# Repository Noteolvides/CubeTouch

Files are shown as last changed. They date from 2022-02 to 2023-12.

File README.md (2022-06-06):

## What is it?
A cube made up of 6 PCBs that when soldered together form a cube universe.
CubeTouch is designed to create a beautiful object from PCBs but giving it all the functionality of a HID device, being able to interact with the computer as if it were a keyboard or any other HID device. 

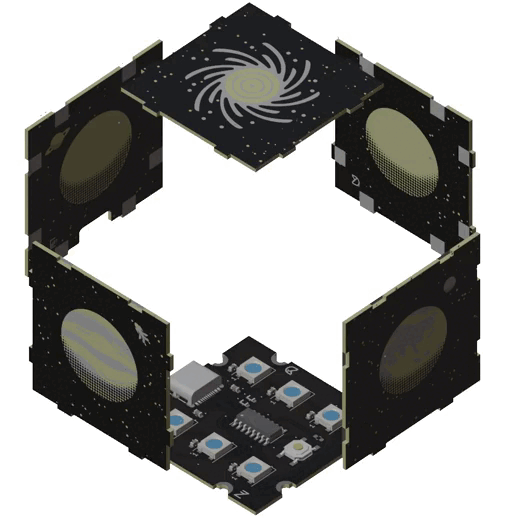
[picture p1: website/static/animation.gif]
Insert Photo here enter image title here


CubeTouch is made up of the **CH552** micontroller and 6 WS2812 LEDs that illuminate the planets thanks to the diffusion of the FR4 material. This device is already loaded with a firmware that when pressing one of the 5 planets will send a combination of keys to the computer. These can be modified on the 

# Documentation and more
CubeTouch has its own [webPage](https://cubetouch.noteolvid.es/) where you can find, how to [program the device](https://cubetouch.noteolvid.es/docs/firstSteps/programming/), [examples](https://cubetouch.noteolvid.es/docs/firstSteps/examples/) and much more😊!

## Examples
### Custom Firmware
Default firmware that comes preload with the package. Its main function is to use as an external keyboard with shortcuts to increase your productivity in your daily work in the computer.
Each face is mapped with a possible combination of 3 keys, and a color to show that the keys were sent.
These can be remapped via the [web interface](https://cubetouch.noteolvid.es/keyRemapping/) thanks to [web serial](https://web.dev/serial/).
### [Easy RGB](https://cubetouch.noteolvid.es/docs/firstSteps/examples/#easy-rgb)
A simple example that receives an RGB hex value and displays it. Send hex color to the Serial Monitor following this format (R,G,B): #0B4F02
### [Chasse Lights](https://cubetouch.noteolvid.es/docs/firstSteps/examples/#chasse-text)
Moving lights.
### [Easy Touch](https://cubetouch.noteolvid.es/docs/firstSteps/examples/#easy-touch)
A simple example that when a face is touch prints the face that has received input from.
### [CDC and Keyboard](https://cubetouch.noteolvid.es/docs/firstSteps/examples/#cdc-and-keyboard)
This example echoes the next character of data it receives via the serial monitor and sends as a key also the next character send.
### [Custom Bootloader](https://cubetouch.noteolvid.es/docs/firstSteps/examples/#custom-bootloader)
This example that shows how to jump to the bootloader address to make it reprogrammable. You can send the character B, or connect the pin 11 to GND.

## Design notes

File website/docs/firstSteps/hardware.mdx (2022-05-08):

---
sidebar_position: 2
---

# Hardware

## Pinout
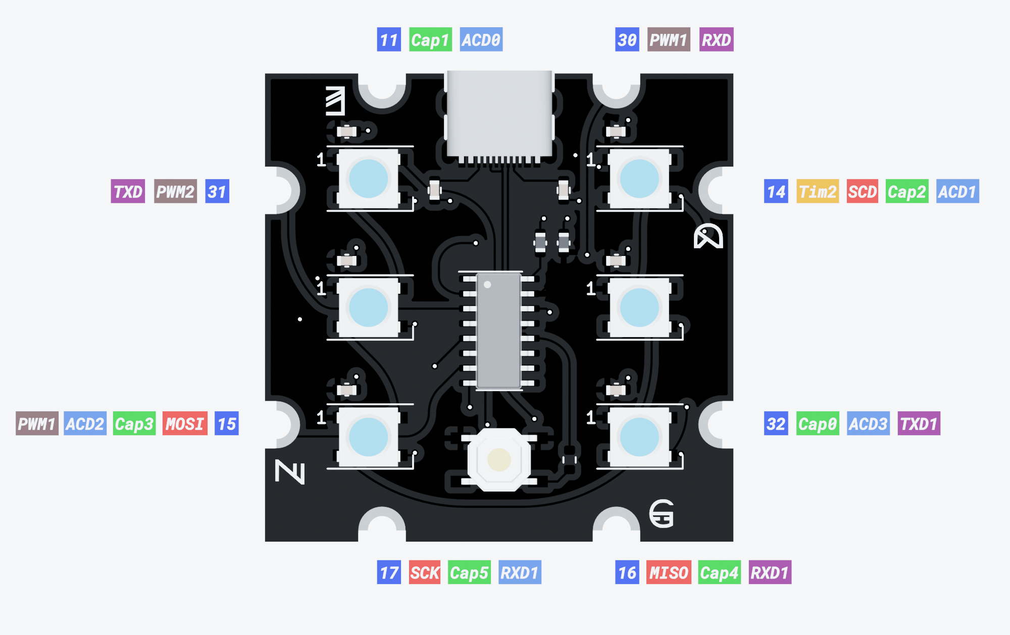
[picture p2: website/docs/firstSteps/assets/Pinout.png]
Pinout


[//]: # (TODO: Add here table with pin capabilities)

## BOM
| **Qty** | **Value** | **LCSC** | **Reference(s)** |
|:---:|:---:|:---:|:---:|
| 8 |  Capacitor 0,1uf  |  C14663  | C1, C2, C3, C4, C5, C6, C7, C8 |
| 6 | WS2812B |  C139127 | D1, D2, D3, D4, D5, D6 |
| 1 | USB_C |  C709357 | J1 |
| 2 | Resistor 5.1K |  C25905  | R1, R2 |
| 1 | Resistor 10K |  C25197  | R3 |
| 1 | SW Tactile Button |  C318884 | SW1 |
| 1 | CH554G |  C114295 | U1 |
## Schematics
> :warning: The shematics and pcb are made with the beta version of kicad 5.99

Download the schematic made with kicad in [GitHub](https://github.com/Noteolvides/CubeTouch/tree/main/Hardware/Bottom).
<embed src={require("./assets/salida.pdf").default} width="100%" height="500" type="application/pdf"/>

## PCB'S

### Top
Download the pcb made with kicad in [GitHub](https://github.com/Noteolvides/CubeTouch/tree/main/Hardware/Top).
<div className="container">
  <div className="row" style={{alignItems: "center"}}>
    Pcb Render top
    Pcb Render top back
  </div>
</div>

### Bottom
Download the pcb made with kicad in [GitHub](https://github.com/Noteolvides/CubeTouch/tree/main/Hardware/Bottom).
<div className="container">
  <div className="row" style={{alignItems: "center"}}>
    Pcb Render top
    Pcb Render top back
  </div>
</div>

### Left
Download the pcb made with kicad in [GitHub](https://github.com/Noteolvides/CubeTouch/tree/main/Hardware/Left).
<div className="container">
  <div className="row" style={{alignItems: "center"}}>
    Pcb Render top
    Pcb Render top back
  </div>
</div>

### Right
Download the pcb made with kicad in [GitHub](https://github.com/Noteolvides/CubeTouch/tree/main/Hardware/Right).
<div className="container">
  <div className="row" style={{alignItems: "center"}}>
    Pcb Render top
    Pcb Render top back
  </div>
</div>

### Front
Download the pcb made with kicad in [GitHub](https://github.com/Noteolvides/CubeTouch/tree/main/Hardware/Front).
<div className="container">
  <div className="row" style={{alignItems: "center"}}>
    Pcb Render top
    Pcb Render top back
  </div>
</div>

### Back
Download the pcb made with kicad in [GitHub](https://github.com/Noteolvides/CubeTouch/tree/main/Hardware/Back).
<div className="container">
  <div className="row" style={{alignItems: "center"}}>
    Pcb Render top
    Pcb Render top back
  </div>
</div>

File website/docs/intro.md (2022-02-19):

---
sidebar_position: 1
---

# Welcome to the docs

Let's start learning about **CubeTouch** in less than 5 minutes.

## Getting Started

You can get you own CubeTouch in  **[Tindie](https://docusaurus.new)** there two versions available the already build  one, or you can build it yourself.

If you have gotten build it your shelf version you can check **[here](https://docusaurus.new)** the video and instructions in how to build it.

Once you have your device ready lest start seeing what it can do.

## Features

The CubeTouch is preloaded with a default firmware that shows all the possibles capabilities of this device.
Some of them are:

- Key press emulation, for shortcuts.
- Communication to the computer via WEB Serial.
- Touch capacitive inputs.
- Key remapping via web interface **[here](https://docusaurus.new)**
- Cool RGB lighting (Why not 😝)

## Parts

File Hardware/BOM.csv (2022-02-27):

Reference(s) | Value | LCSC | Qty
C1, C2, C3, C4, C5, C6, C7, C8 | Capacitor 0,1uf | C14663 | 8
D1, D2, D3, D4, D5, D6 | WS2812B | C139127 | 6
J1 | USB_C | C709357 | 1
R1, R2 | Resistor 5.1K | C25905 | 2
R3 | Resistor 10K | C25197 | 1
SW1 | SW Tactile Button | C318884 | 1
U1 | CH554G | C114295 | 1

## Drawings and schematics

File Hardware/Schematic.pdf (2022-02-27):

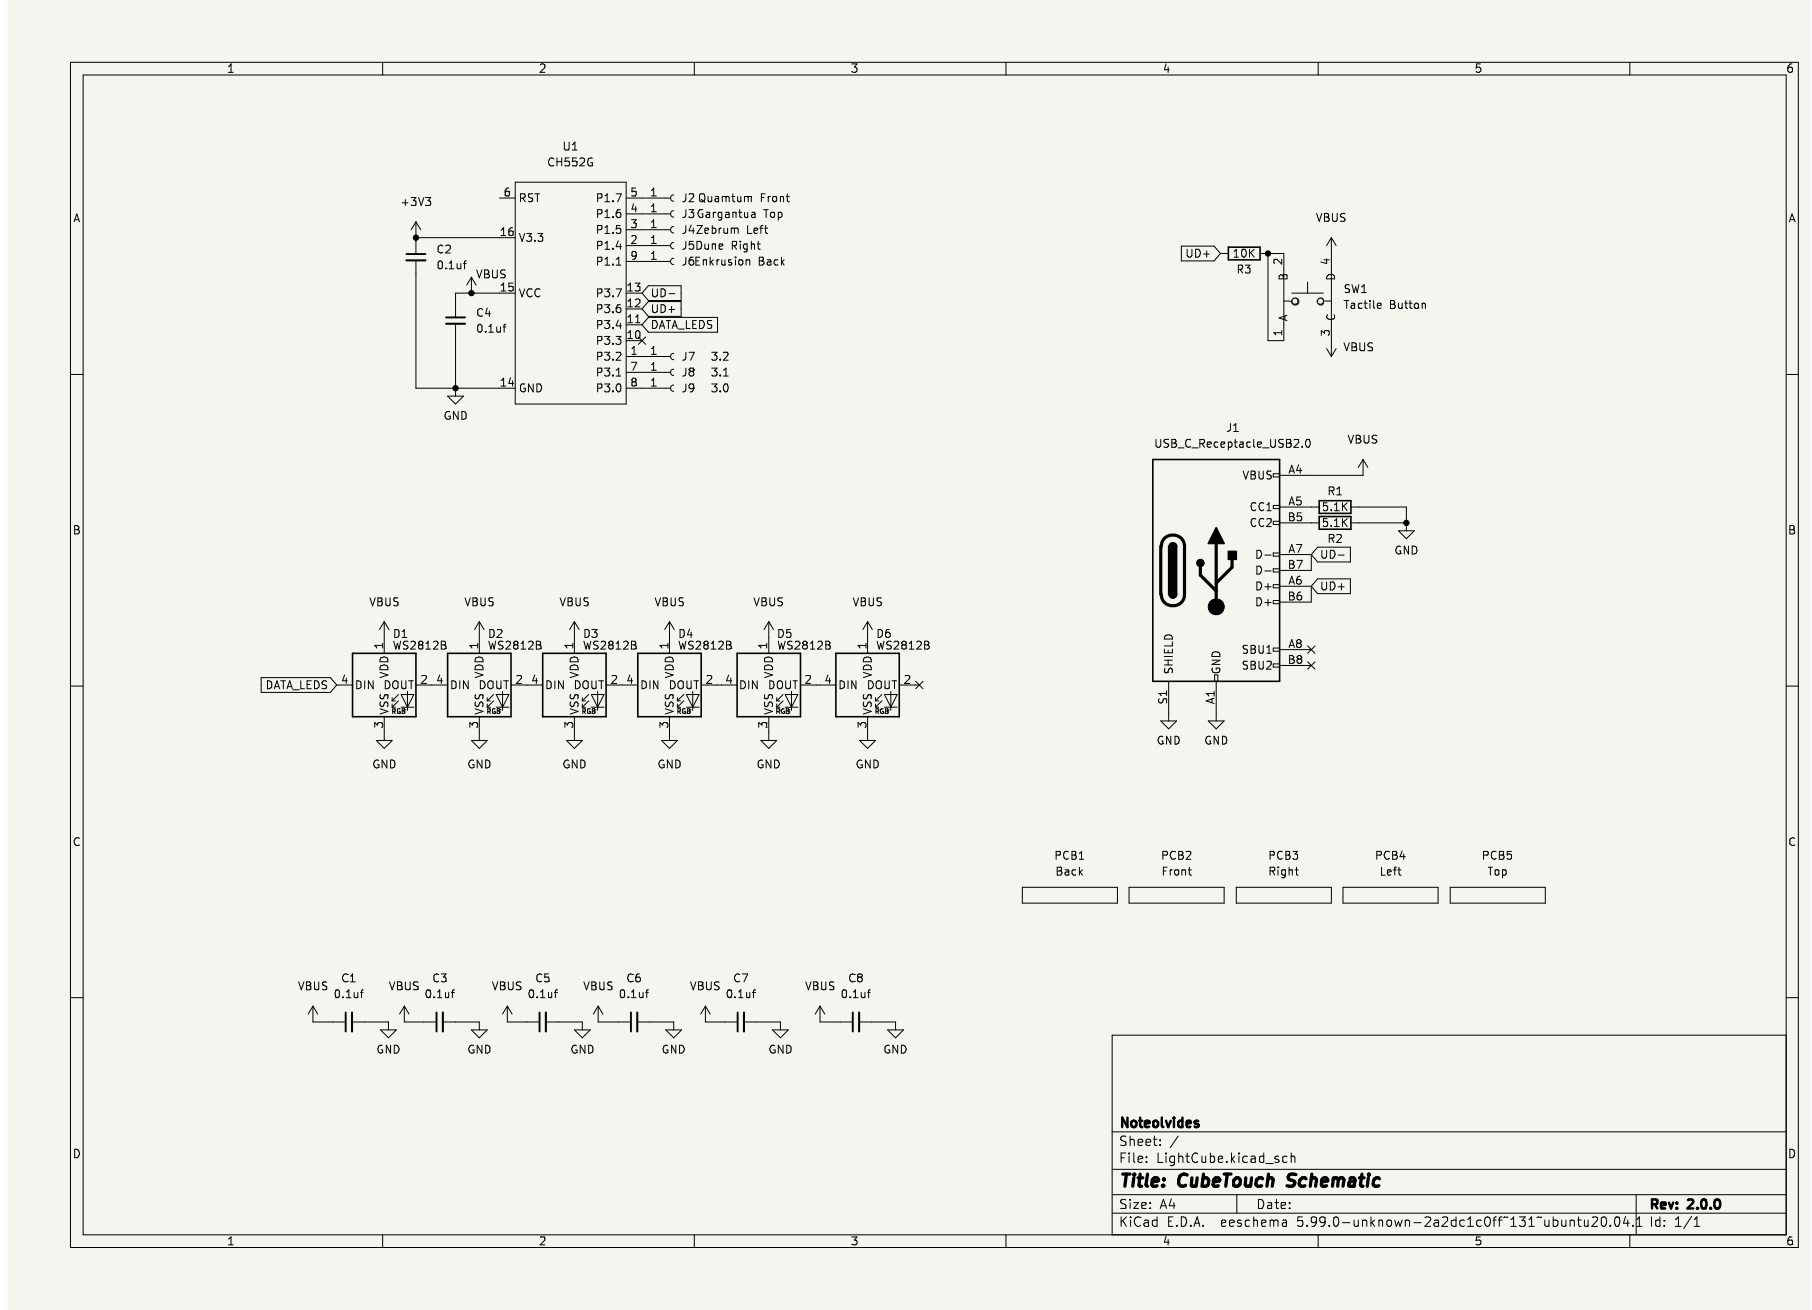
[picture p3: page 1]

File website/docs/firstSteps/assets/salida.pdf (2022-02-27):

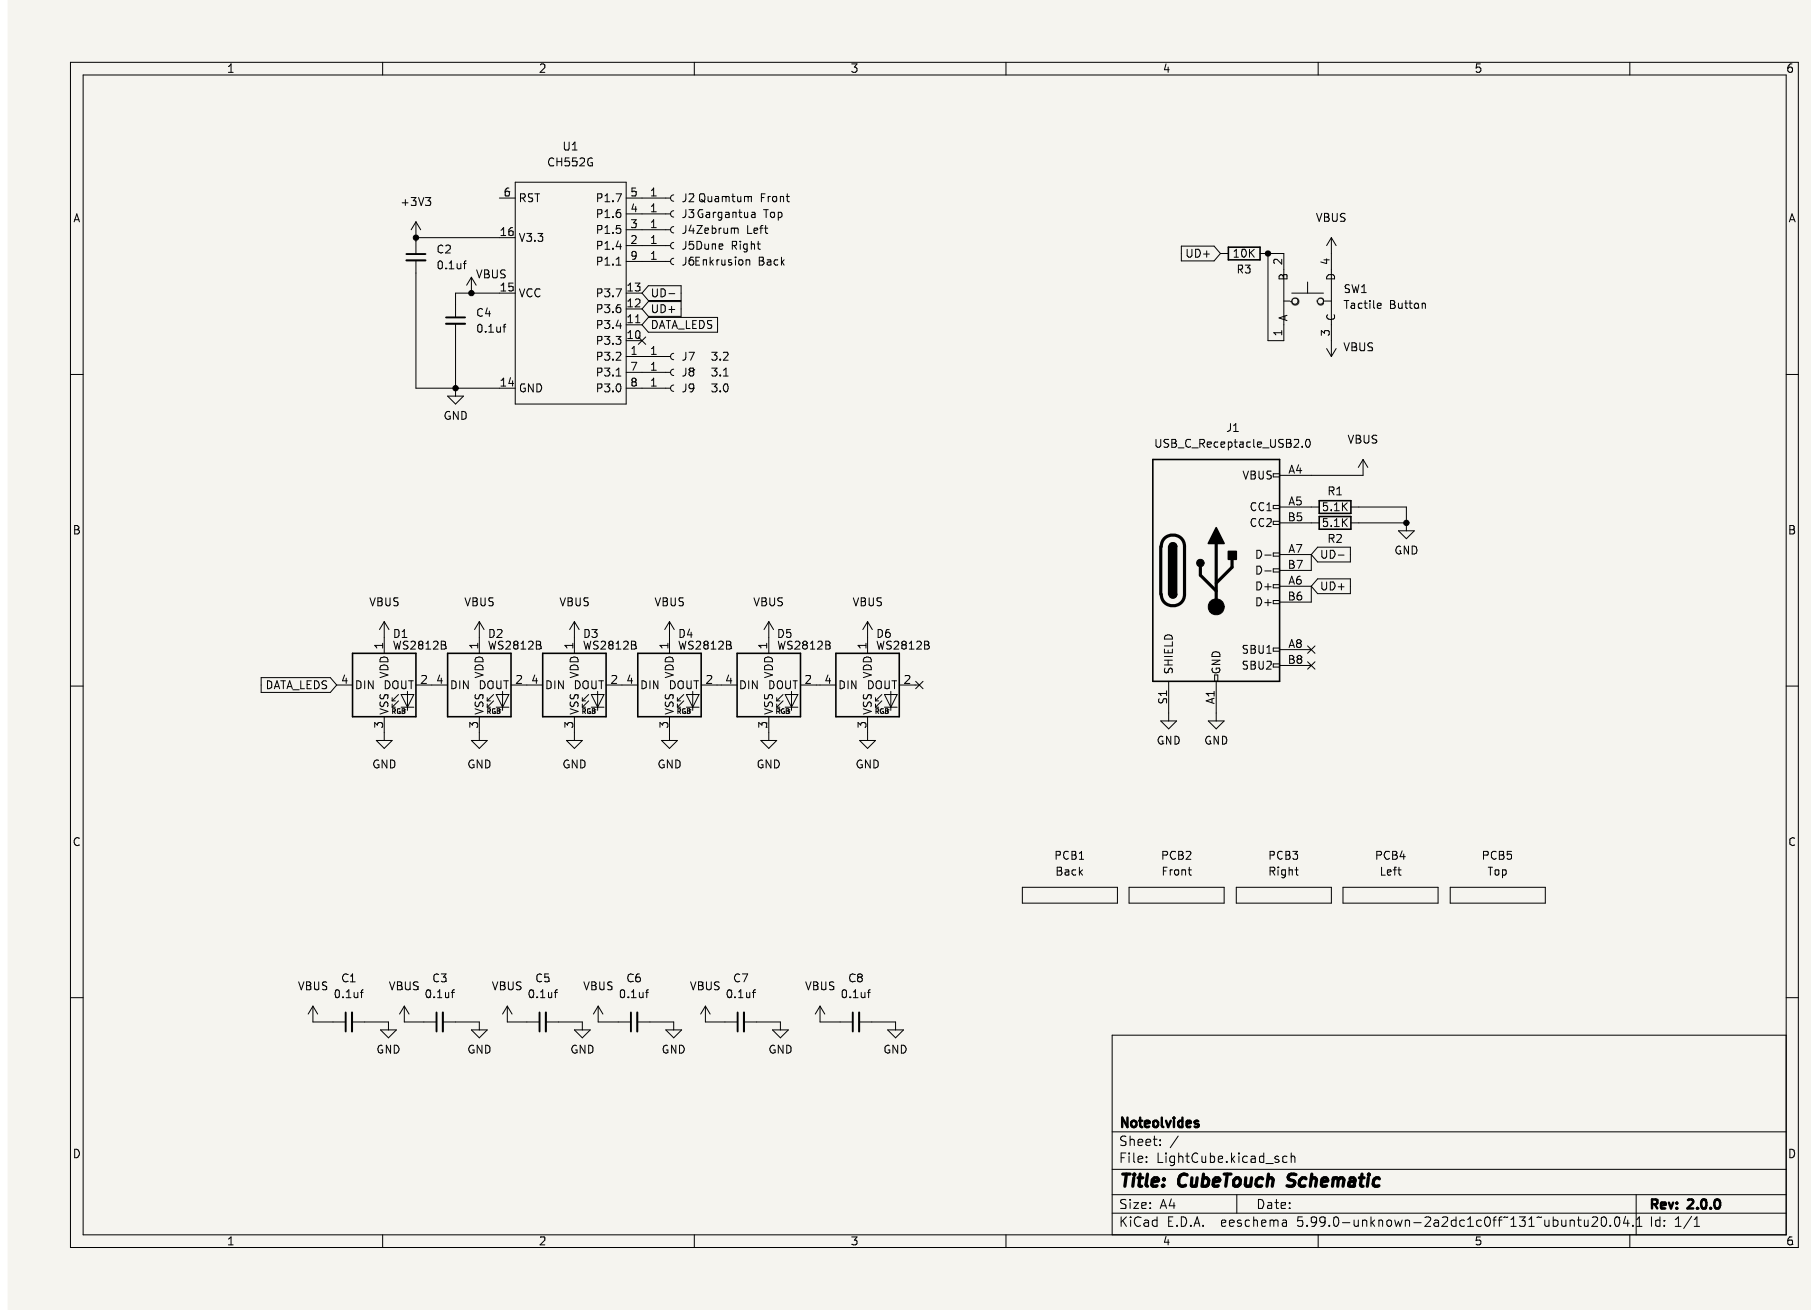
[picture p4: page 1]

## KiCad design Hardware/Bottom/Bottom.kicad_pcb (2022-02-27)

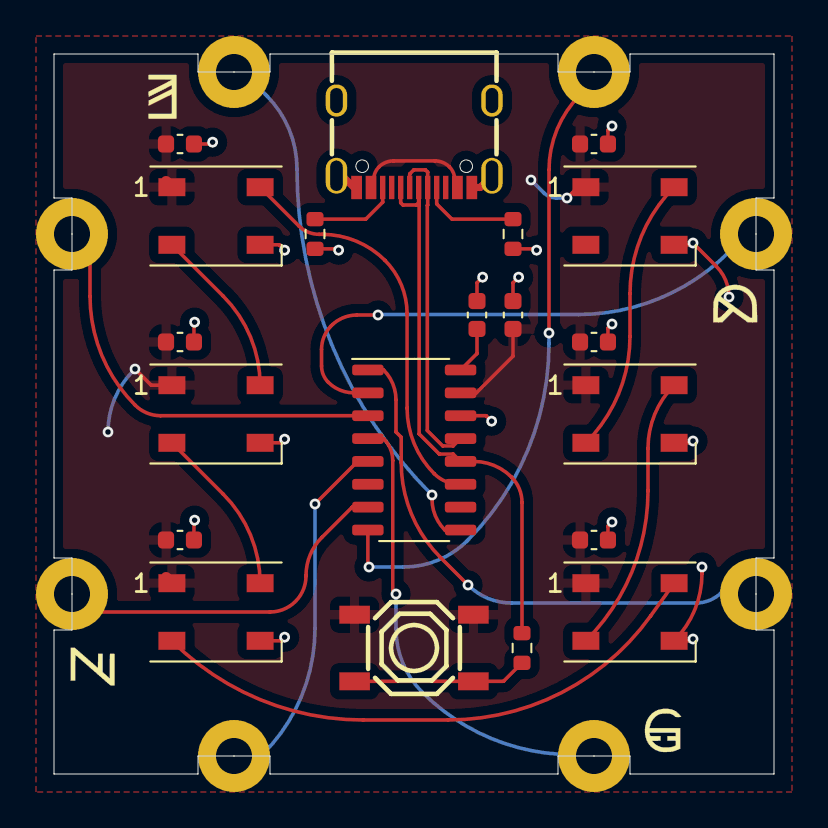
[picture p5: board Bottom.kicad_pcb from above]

Board: 2 copper layers, 40.0 x 40.0 mm, 28 parts (0 on the bottom side), 22 nets.

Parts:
C1, C2, C3, C4, C5, C6, C7, C8: 0.1uf; C_0603_1608Metric
D1, D2, D3, D4, D5, D6: WS2812B; LED_WS2812B_PLCC4_5.0x5.0mm_P3.2mm
J1: USB_C_Receptacle_USB2.0; USB-C-SMD_KH-TYPE-C-16P
J2: Quamtum Front; Castelated
J3: Gargantua Top; Castelated
J4: Zebrum Left; Castelated
J5: Dune Right; Castelated
J6: Enkrusion Back; Castelated
J7: 3.2; Castelated
J8: 3.1; Castelated
J9: 3.0; Castelated
R1, R2: 5.1K; R_0603_1608Metric
R3: 10K; R_0603_1608Metric
SW1: Tactile Button; SW-SMD_4P-L5.1-W5.1-P3.70-LS6.5-TL-2
U1: CH552G; SO-16_3.9x9.9mm_P1.27mm

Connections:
+3V3: C2.1, U1.16 (V3.3)
DATA_LEDS: D1.4 (DIN), U1.11 (P3.4)
GND: C1.2, C2.2, C3.2, C4.2, C5.2, C6.2, C7.2, C8.2, D1.3 (VSS), D2.3 (VSS), D3.3 (VSS), D4.3 (VSS), D5.3 (VSS), D6.3 (VSS), J1.A1 (GND), J1.A12 (GND), J1.B1 (GND), J1.B12 (GND), J1.S1 (SHIELD), R1.2, R2.2, U1.14 (GND)
unnamed: D1.2 (DOUT), D2.4 (DIN)
unnamed: D2.2 (DOUT), D3.4 (DIN)
unnamed: D3.2 (DOUT), D4.4 (DIN)
unnamed: D4.2 (DOUT), D5.4 (DIN)
unnamed: D5.2 (DOUT), D6.4 (DIN)
unnamed: J1.A5 (CC1), R1.1
unnamed: J1.B5 (CC2), R2.1
unnamed: J2.1, U1.5 (P1.7)
unnamed: J3.1, U1.4 (P1.6)
unnamed: J4.1, U1.3 (P1.5)
unnamed: J5.1, U1.2 (P1.5)
unnamed: J6.1, U1.9 (P1.1)
unnamed: J7.1, U1.1 (P3.2)
unnamed: J8.1, U1.7 (P3.1)
unnamed: J9.1, U1.8 (P3.0)
unnamed: R3.2, SW1.1 (A), SW1.2 (B)
UD+: J1.A6 (D+), J1.B6 (D+), R3.1, U1.12 (P3.6)
UD-: J1.A7 (D-), J1.B7 (D-), U1.13 (P3.7)
VBUS: C1.1, C3.1, C4.1, C5.1, C6.1, C7.1, C8.1, D1.1 (VDD), D2.1 (VDD), D3.1 (VDD), D4.1 (VDD), D5.1 (VDD), D6.1 (VDD), J1.A4 (VBUS), J1.A9 (VBUS), J1.B4 (VBUS), J1.B9 (VBUS), SW1.3 (C), SW1.4 (D), U1.15 (VCC)

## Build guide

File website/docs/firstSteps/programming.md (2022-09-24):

---
sidebar_position: 1
---

# Program your device

CubeTouch is build with a ch552 microcontroller, a super cheap but powerful microcontroller.

The *"official"* compiler for this microcontroller is the CK51 but this compiler is only available as paid software.

That's why people like **[Blinkinlabs](https://github.com/Blinkinlabs/ch554_sdcc)**
and **[DeqingSun](https://github.com/DeqingSun/ch55xduino)** have created a port of the CH554 SDK, from Keli C51 to
SDCC (a free compiler).

The easiest way to start programing the **CubeTouch** is using **[ch55xduino](https://github.com/DeqingSun/ch55xduino)**
port for Arduino and this will be the follow explanation here.

You can follow the  **[ch55xduino](https://github.com/DeqingSun/ch55xduino)**  guide or stick with the following one
that will go a bit more in depth.

## Arduino board Integration.

First you must obtain the arduino IDE you can get it from **[here](https://www.arduino.cc/en/software)**.

Automatic IDE integration is supported via the Arduino Boards Manager. This is the recommended way of installation now.

Start the Arduino-IDE. In *File->Preferences*, *Settings* tab, enter

> https://raw.githubusercontent.com/DeqingSun/ch55xduino/ch55xduino/package_ch55xduino_mcs51_index.json

as an *Additional Boards Manager URL*.

* Open *Tools->Board:...->Boards Manager*
* Find Ch55xduino by typing 'ch' into the search line
* Click on the list entry
* Click on *Install*.

Now you should find a new entry *CH55x Boards* in the list at.

The smarter way to start creating you own code is to read some of the examples created for the CubeTouch. You can
check it out in the followings pages or **[here](https://github.com/Noteolvides/CubeTouch-Software/tree/master/CDC_KEYBOARD)**.

### For linux users

By default, Linux will not expose enough permission for Arduino to upload the code with the USB bootloader. Copy the
following code as a file with the name 99-ch55xbl.rules to /etc/udev/rules.d/. Otherwise, the upload tool may not find
the bootloader device.

```bash
# CH55x bootloader
# copy to /etc/udev/rules.d/

SUBSYSTEM=="usb", ATTRS{idVendor}=="4348", ATTRS{idProduct}=="55e0", MODE="0666"
```
and execute 

```bash
sudo usermod -a -G dialout $USER
```

### For windows Users.

Zadig image

[Zadig](https://zadig.akeo.ie/) is the recommended tool to install drivers in Windows. The bootloader (4348,55E0) should
be installed with libusb-win32 driver (WinUSB driver may not work on some computer).

Zadig CDC image

You can use USB Serial (CDC) driver for the default CDC USB stack (1209,C550).

If you tried to emulate another type of USB device without changing the PID/VID, you may need to uninstall the device
before installing a new driver.

### Warnings ⚠️

To reprogram the CubeTouch we use the Ch55xduino USB bootloader this uses
the **[USB CDC](https://en.wikipedia.org/wiki/USB_communications_device_class)** that's why you can use any examples
that Ch55xduino provides except the ones that change the USB stack, ie:

- CDCinUserCode 📛
- CMSIS_DAP 📛
- HIDKeyboard 📛
- MassStorage 📛
- NoUsbExample 📛

If you want to change or use the examples mentioned above and want to reprogram the device later you have to add a back
door to be able to reprogram the device. For example calling this function when an input goes high.

```c
void jump_to_bootloader() {
    USB_INT_EN = 0;   // USB interrupt disable
    USB_CTRL = 0x06;  // USB base control Reset
    delay(100);
    EA = 0;                    // Disable all interrupts
    __asm__("lcall #0x3800");  // Jump to bootloader code
    while (1);
}
```

Furthermore, CubeTouch provide a **CDC + HID Keyboard USB** example that enables to use the virtual serial and the
keyboard emulation without losing the ability to reprogram the device. You can check it out
**[here](https://github.com/Noteolvides/CubeTouch-Software/tree/master/CDC_KEYBOARD)**.

#### Unreprogrammable device

If you have uploaded unreprogrammable code to your device you can reprogram it by desoldering the bottom pcb joints and
exposing the reprogram button. Then you must press the button while inserting the usb in to the computer this would make
the device jump automatically to the bootloader address.

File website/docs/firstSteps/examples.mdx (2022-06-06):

# Examples

## Custom Firmware
Default firmware that comes preload with the package. Its main function is to use as an external keyboard with shortcuts to increase your productivity in your daily work in the computer.
Each face is mapped with a possible combination of 3 keys, and a color to show that the keys were sent.
These can be remapped via the [web interface](https://cubetouch.noteolvid.es/keyRemapping/) thanks to [web serial](https://web.dev/serial/).

<details>
  <summary>Check the code 🖥</summary>

  ```cpp reference
  https://github.com/Noteolvides/CubeTouch/blob/main/Examples/CustomFirmware/CustomFirmware.ino
  ```

</details>

## Easy RGB
A simple example that receives an RGB hex value and displays it.
Send hex color to the Serial Monitor following this format (R,G,B): #0B4F02

<details>
  <summary>Check the code 🖥</summary>

  ```cpp reference
  https://github.com/Noteolvides/CubeTouch/blob/main/Examples/EasyRGB/EasyRGB.ino
  ```

</details>

<div className="container">
  <div className="row" style={{alignItems: "center"}}>
    How To Send RGB CODE
    Result Photo
  </div>
</div>

## Chasse Text
No configuration, just upload the sketch and enjoy the beautiful colors.
<details>
  <summary>Check the code 🖥</summary>

  ```cpp reference
  https://github.com/Noteolvides/CubeTouch/blob/main/Examples/ChasseTest/ChasseTest.ino
  ```

</details>

<div style={{display: "flex", justifyContent: "center"}}>
  <video autoPlay muted loop src={require('./assets/ChaseTest.mp4').default}/>
</div>

## Touch Graph
A simple sketch that plots all the values coming from the 5 capacitive buttons.

<details>
  <summary>Check the code 🖥</summary>

  ```cpp reference
  https://github.com/Noteolvides/CubeTouch/blob/main/Examples/TouchGraph/TouchGraph.ino
  ```

</details>

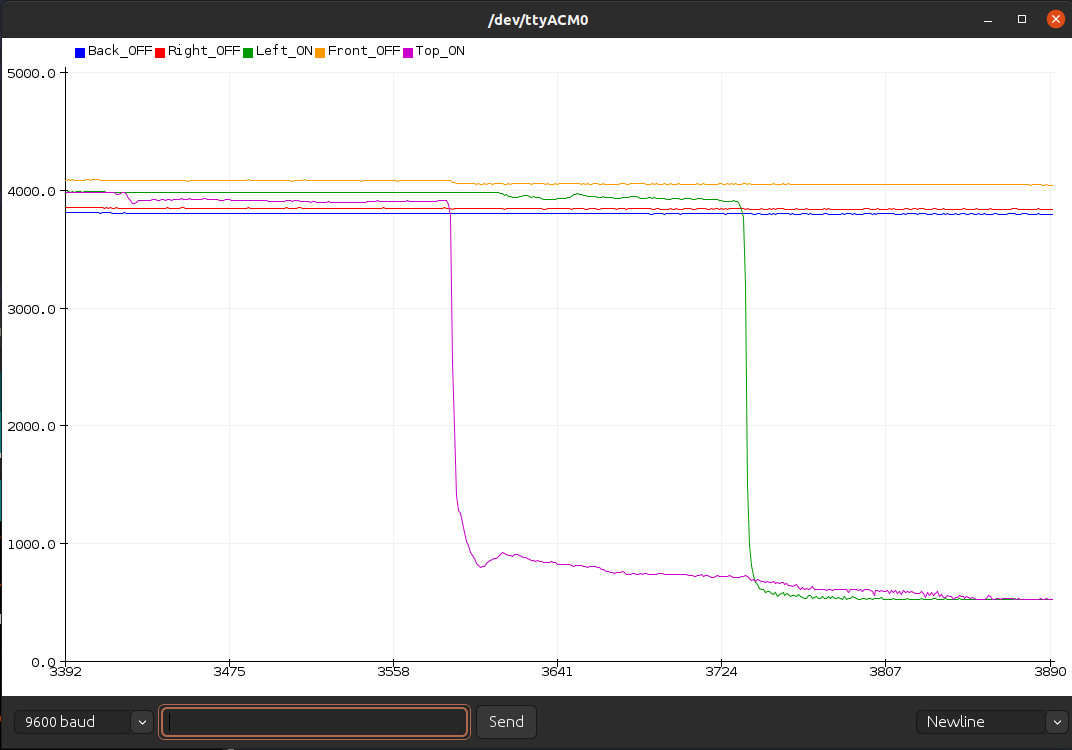
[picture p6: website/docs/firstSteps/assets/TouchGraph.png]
Tocuh


## CDC and Keyboard
This example echoes the next character of data it receives via the serial monitor and sends as a key also the next character send.

<details>
  <summary>Check the code 🖥</summary>

  ```cpp reference
  https://github.com/Noteolvides/CubeTouch/blob/main/Examples/CDC_KEYBOARD/CDC_KEYBOARD.ino
  ```

</details>

<div className="margin-bottom--lg" style={{display: "flex", justifyContent: "center"}}>
  <video style={{width: "100%"}} autoPlay muted loop src={require('./assets/CDC_KEYBOARD.mp4').default}/>
</div>

> :warning: This example needs to be compiled with a **USER USB** setting
> Tools--> USB Settings--> USER CODE w/148 USB Ram

## Custom bootloader
This example that shows how to jump to the bootloader address to make it reprogrammable.
You can send the character B, or connect the pin 11 to GND.

<details>
  <summary>Check the code 🖥</summary>

  ```cpp reference
  https://github.com/Noteolvides/CubeTouch/blob/main/Examples/CustomBootloader/CustomBootloader.ino
  ```

</details>

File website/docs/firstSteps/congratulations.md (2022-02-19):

---
sidebar_position: 6
---

# Congratulations!

You have just learned the **basics of Docusaurus** and made some changes to the **initial template**.

Docusaurus has **much more to offer**!

Anything **unclear** or **buggy** in this tutorial? [Please report it!](https://github.com/facebook/docusaurus/discussions/4610)

## What's next?

- Read the [official documentation](https://docusaurus.io/).
- Add a custom [Design and Layout](https://docusaurus.io/docs/styling-layout)
- Add a [search bar](https://docusaurus.io/docs/search)
- Find inspirations in the [Docusaurus showcase](https://docusaurus.io/showcase)
- Get involved in the [Docusaurus Community](https://docusaurus.io/community/support)

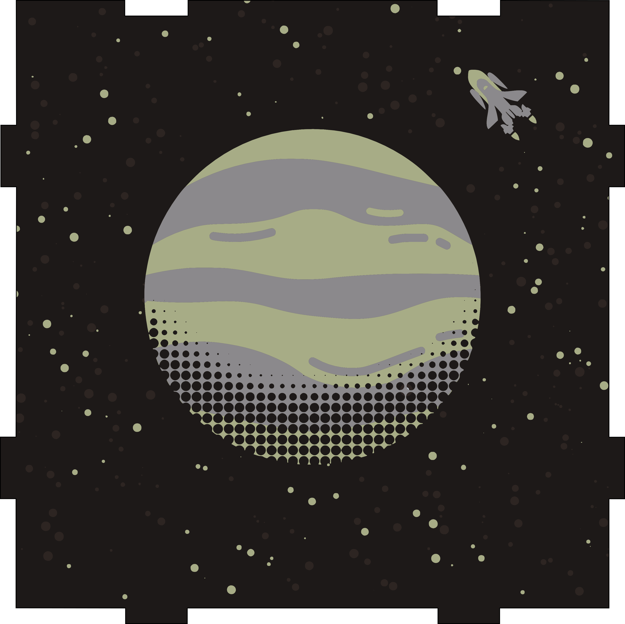
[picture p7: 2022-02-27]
website/docs/firstSteps/assets/Left/Left.png

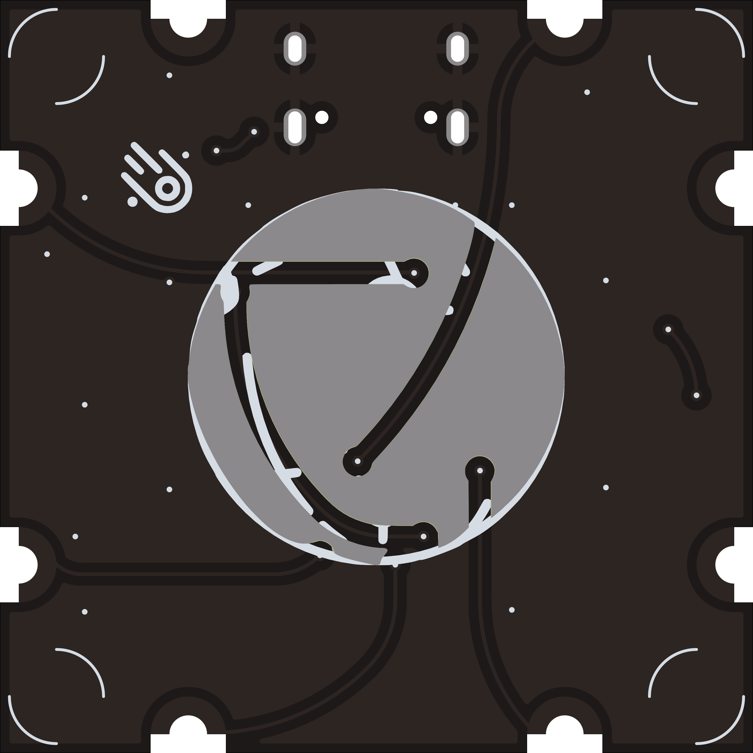
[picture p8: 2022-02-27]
website/docs/firstSteps/assets/Bottom/Bottom-back.png

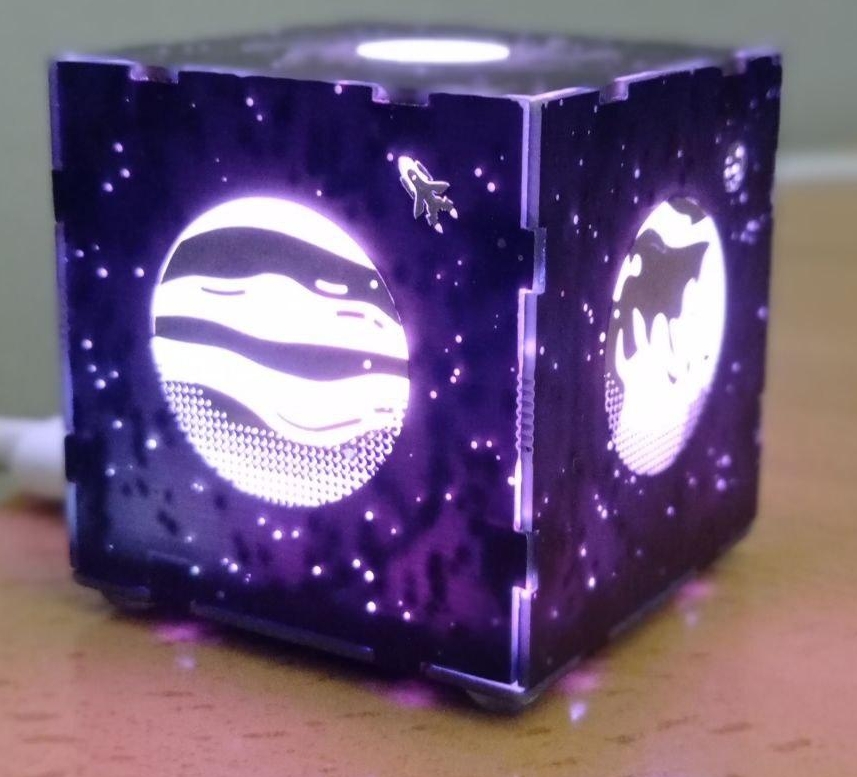
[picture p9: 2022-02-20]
website/docs/firstSteps/assets/EasyRGBPhoto.jpg

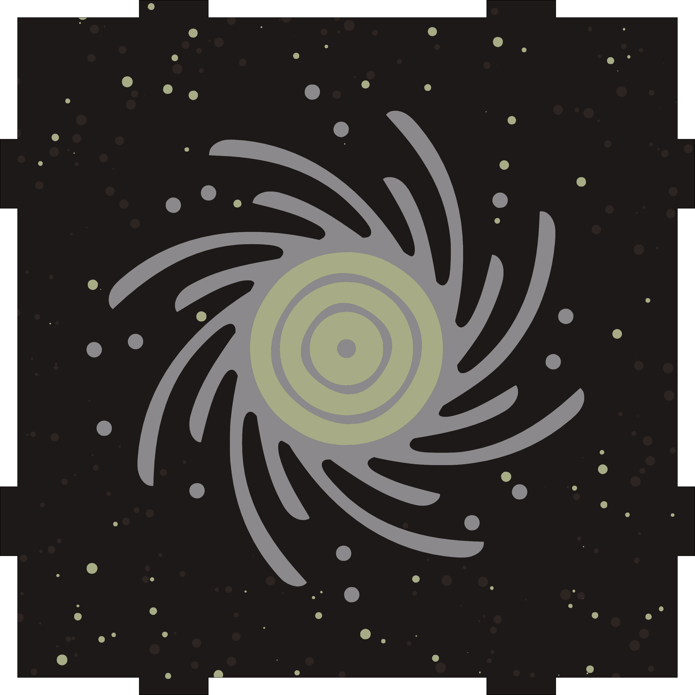
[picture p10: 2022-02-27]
website/docs/firstSteps/assets/Top/Top.png

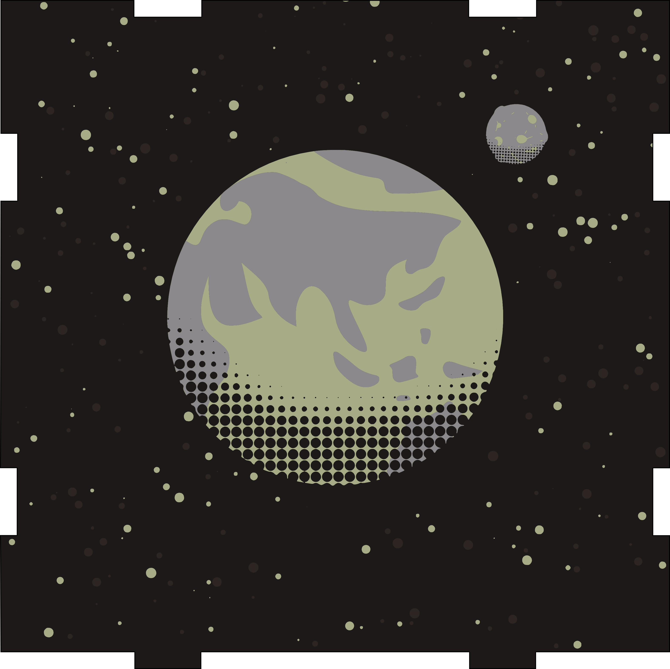
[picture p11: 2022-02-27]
website/docs/firstSteps/assets/Front/Fron.png

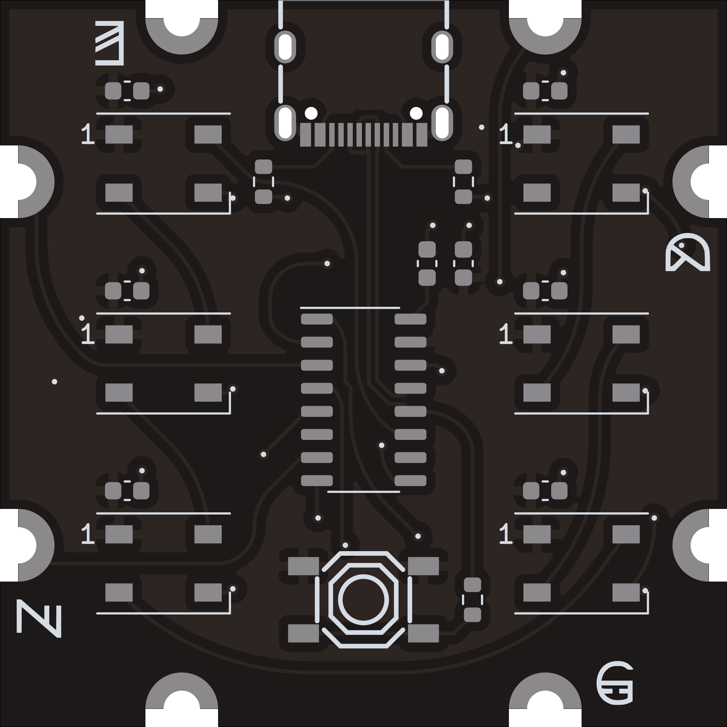
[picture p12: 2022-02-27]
website/docs/firstSteps/assets/Bottom/Bottom.png

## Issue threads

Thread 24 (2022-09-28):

Please add PCB and GERBER files for whole cube

arduino12, 2022-09-28:
**Amazing work!!!**

Can you please add to the repo the PCB and GERBER files of the whole cube (the one showd in the video)?
I only found [individual PCB files](https://github.com/Noteolvides/CubeTouch/tree/main/Hardware) for each cube face:

I will surely contribute some code examples after I build my own soon :)

**Thanks! :)**

Noteolvides, 2022-09-28:
Hi, all the info is here!
https://github.com/Noteolvides/CubeTouch
This is the main repo also, you will be able to buy it soon if you want to support me!
More info here soon.
https://cubetouch.noteolvid.es/

Closed 2022-09-28.

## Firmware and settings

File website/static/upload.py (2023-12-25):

import os
import time
import serial.tools.list_ports
import serial

ser = serial.Serial(timeout=10)


def main():
    os.system("$HOME/bin/arduino-cli upload -p /dev/ttyUSB0 --fqbn CH55xDuino:mcs51:ch552 -i CustomFirmware.hex")

    time.sleep(0.5)
    print("Try to connect some device cubetouch")
    ports = list(serial.tools.list_ports.comports())
    for p in ports:
        if p.vid == 0x1209 and p.pid == 0xC6be:
            print("Found Device Serial")
            ser.port = p.device
            ser.open()
            firstFace = bytes([67, 0, 28, 18, 24, 122, 114, 58])

            secondFace = bytes([67, 1, 4, 21, 8, 128, 62, 62])

            thirdFace = bytes([67, 2, 23, 11, 8, 159, 159, 159])

            forthFace = bytes([67, 3, 5, 8, 22, 105, 167, 67])

            fifthFace = bytes([67, 4, 11, 12, 0, 85, 90, 159])

            ser.write(firstFace)
            time.sleep(0.1)
            ser.write(secondFace)
            time.sleep(0.1)
            ser.write(thirdFace)
            time.sleep(0.1)
            ser.write(forthFace)
            time.sleep(0.1)
            ser.write(fifthFace)
            time.sleep(0.1)
            ser.close()
            print("All data sent")


if __name__ == '__main__':
    main()

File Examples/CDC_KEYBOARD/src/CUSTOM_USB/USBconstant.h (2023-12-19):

#ifndef __CONST_DATA_H__
#define __CONST_DATA_H__

// clang-format off
#include <stdint.h>
#include "include/ch5xx.h"
#include "include/ch5xx_usb.h"
#include "usbCommonDescriptors/StdDescriptors.h"
#include "usbCommonDescriptors/CDCClassCommon.h"
#include "usbCommonDescriptors/HIDClassCommon.h"
// clang-format on

#define EP0_ADDR 0
#define EP1_ADDR 10
#define EP2_ADDR 20
#define EP3_ADDR 160

#define SET_LINE_CODING                                                        \
  0X20 // Configures DTE rate, stop-bits, parity, and number-of-character
#define GET_LINE_CODING                                                        \
  0X21 // This request allows the host to find out the currently configured line
       // coding.
#define SET_CONTROL_LINE_STATE                                                 \
  0X22 // This request generates RS-232/V.24 style control signals.

#define CDC_NOTIFICATION_EPADDR 0x81
#define CDC_NOTIFICATION_EPSIZE 0x08
#define CDC_TX_EPADDR 0x82
#define CDC_RX_EPADDR 0x02
#define CDC_TXRX_EPSIZE 0x40

#define KEYBOARD_EPADDR 0x83
#define KEYBOARD_LED_EPADDR 0x03
#define KEYBOARD_EPSIZE 8

/* Type Defines: */
/** Type define for the device configuration descriptor structure. This must be
 * defined in the application code, as the configuration descriptor contains
 * several sub-descriptors which vary between devices, and which describe the
 * device's usage to the host.
 */
typedef struct {
  USB_Descriptor_Configuration_Header_t Config;
  USB_Descriptor_Interface_Association_t CDC_IAD;

  // CDC Command Interface
  USB_Descriptor_Interface_t CDC_CCI_Interface;
  USB_CDC_Descriptor_FunctionalHeader_t CDC_Functional_Header;
  USB_CDC_Descriptor_FunctionalACM_t CDC_Functional_ACM;
  USB_CDC_Descriptor_FunctionalUnion_t CDC_Functional_Union;
  USB_Descriptor_Endpoint_t CDC_NotificationEndpoint;

  // CDC Data Interface
  USB_Descriptor_Interface_t CDC_DCI_Interface;
  USB_Descriptor_Endpoint_t CDC_DataOutEndpoint;
  USB_Descriptor_Endpoint_t CDC_DataInEndpoint;

  // Keyboard HID Interface
  USB_Descriptor_Interface_t HID_Interface;
  USB_HID_Descriptor_HID_t HID_KeyboardHID;
  USB_Descriptor_Endpoint_t HID_ReportINEndpoint;
} USB_Descriptor_Configuration_t;

/** Enum for the device interface descriptor IDs within the device. Each
 * interface descriptor should have a unique ID index associated with it, which
 * can be used to refer to the interface from other descriptors.
 */
enum InterfaceDescriptors_t {
  INTERFACE_ID_CDC_CCI = 0, /**< CDC CCI interface descriptor ID */
  INTERFACE_ID_CDC_DCI = 1, /**< CDC DCI interface descriptor ID */
};

extern __code USB_Descriptor_Device_t DeviceDescriptor;
extern __code USB_Descriptor_Configuration_t ConfigurationDescriptor;
extern __code uint8_t ReportDescriptor[];
extern __code uint8_t LanguageDescriptor[];
extern __code uint16_t SerialDescriptor[];
extern __code uint16_t ProductDescriptor[];
extern __code uint16_t CDCDescriptor[];
extern __code uint16_t ManufacturerDescriptor[];

#endif

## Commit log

2022-02-27 Added Hardware Files
    [BOM.csv, Back.kicad_pcb, Bottom.kicad_pcb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]
2023-12-14 working new arduino core
2023-12-15 refactor: remove prints
2023-12-15 refactor: leds
2023-12-19 fix: reading of memory
    [ChasseTest.ino, CustomFirmware.ino]
2023-12-25 feat: change manual page and fix upload of firmware and upload script
    [upload.py]
